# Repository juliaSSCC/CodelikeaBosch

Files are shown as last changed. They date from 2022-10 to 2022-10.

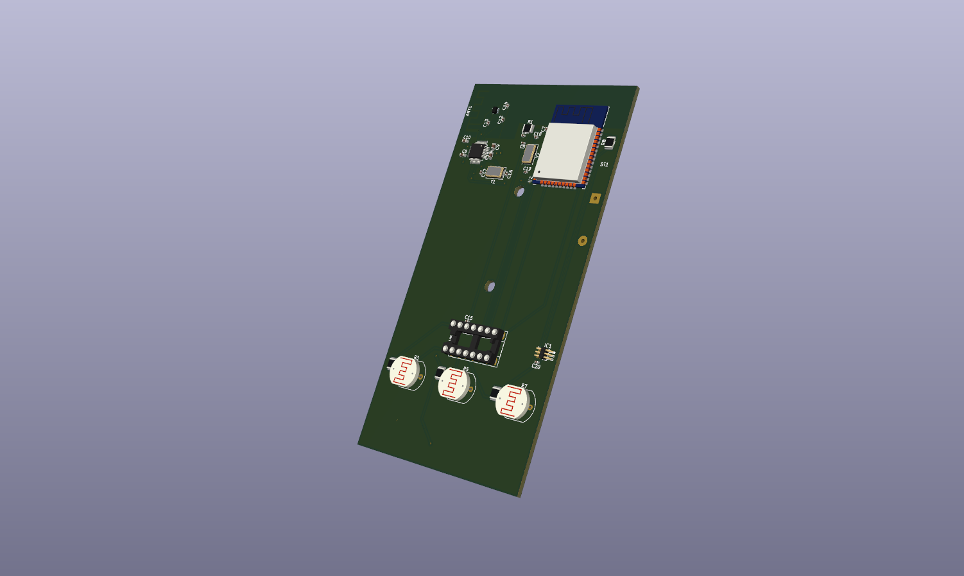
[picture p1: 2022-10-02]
board.png

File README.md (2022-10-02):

# Code #LikeABosch
## Features

### ESP32 based

* ESP32-WROOM-32D Microcontroller 
* Deep sleep mode (10uA)

### Smart position tracking

* BLE to better track postion
    * RSSI tracker for postion

### Smart temperature management

* Base temperature for each room
* Comfort temperature for each room

### Smart lighting

* Turn lights off in empty rooms
* LDR to measure light level
    * Three sensosrs to better capture the whole ambient

### Zigbee Transceiver

* Low power
* Deep Sleep mode (0.02uA)

### Supervisory system

* Shows current temperature
* Shows target temperature
* Shows ocupation
* Light level
* To be integrated to HA

### Power Supply

* Battery powered 3x(AAA)
* Buck converter (3.3V and 1.8V)

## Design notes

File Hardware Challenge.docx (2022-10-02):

João Anastácio da Rocha Almeida

Júlia Stutz Souza Carneiro de Campos

Introduction:

For our smart hardware project, our main goal in the winter is to use a base temperature choose by the house owner, for example 15 °C, in each room and then, predict by Markov Chain where and when the person is going to be during the day and in that way, the room temperature is going to be sensed by a TMP126 sensor and raised by an actuator (smart valve to turn on the heather) to put the temperature in a comfortable value, around 22 °C. We are also tracking the person’s position using Bluetooth Low Energy connected to a smart band and when someone enters the room, the lights will turn on depending on the LDR sensor to measure light level. That way, we decided to create a PCB (printed circuit board) with an ESP microcontroller, and our aim when talking about the user, is to decrease the gas and electricity consumption while being comfortable.

Project Bases:

The Markov chain is a mathematical model used to predict a next state based only on the current state, it is built upon the probability observed in a set of previous states used as training. In our research, we managed to find Markov chain implemented in use cases in microcontrollers, so it’s possible to used it in our routine prediction.

Each room is going to have a PCB (printed circuit board) with an ESP32-WROOM-32, 3 LDR sensors, 1 TMP126 sensor and 1 Low Power 2.4GHz Transceiver for ZigBee for the connections between all the ESPs in the house and a main server having the Markov Chain AI. We’ll be using 3 batteries to supply each PCB.

The ESP is perfect for this application, because it has a Bluetooth Low Energy, it is easy to configure and program, consequently, is easier to provide assistance and maintenance. It would be possible to add more features in the future, like a hydraulic system or safety project. During the design, we chose the ESP32-WROOM-32, because of the easiness, there is a lot of material for it, schematics, example, debug board, but in the real development it is not recommended since it’s.

TMP126 Low-Power is a temperature sensor, it has a configurable precision that defines the maximum and minimum range, we chose the excellent precision of -+0.4°C, which was the key factor, is very cheap, low power, is a different solution in the market and already has the SPI interface. Also, the LDR photoresistor is the most known way of sense the presence of light, is very easy to implement and is cheap, in conclusion, meets all needs.

For the transceiver communication between the microcontrollers, we are using the IC 2.4GHz Transceiver for ZigBee, and we chose the ZigBee/IEEE 802.15.4 protocol, because of the short distance reach, unlike LoRa that could have further interference, but still has a bigger range than Bluetooth, the delay is around 15ms-30ms which is low compared to Wi-Fi, is cheap, easy to configure and maintain compared to a Cellular IoT, and the low-power consumption, that usually works with 3.3V. Two AA batteries usually last 5 months and 2 years.

The installation is available and not that hard, after configuring the devices and the communication between them, the PCB is going to be added in the middle of the room, ideally attached to the ceiling. We chose this spot especially thinking of being far from heathers, the windows and the possibility of putting away from air conditioning. Since the project is about comfortable and, saving more money and energy, we thought in keep even more battery life by using sleep mode, so the price of energy spent is very low.

Cost:

The total cost of the PCB is 19.38 euros (€) per board to develop 1000 considering the manufacture and the components.

Gas Consumption Calculation:

We defined a house with an area of 100m² and 2.5m of height, so the total volume is 250m³. If we consider a big room in this house having 30m² (30 m²*2.5m = 75 m³) the volume is 30% of the total.

1 person/house:

Considering that the person stays in the biggest room for most of the time, the table of consumption is:

Gas Consumption (m^3/h) | Heat load (KW/h) | Efficiency of gas boiler (%) | Calorific Value of Gas (KW/m^3) | Volume (m^3) | Heat loss | Delta T (°C)
1,155990752 | 9,8837209 | 90 | 9,5 | 250 | 1 | 34
0,917992656 | 7,8488372 | 90 | 9,5 | 250 | 1 | 27

Expected Average Temp (°C) | Day Average Temp (°C) | Gas Cons. Per day (m^3) | Solution: Gas Cons. Per day (m^3)
22 | -12 | 27,74378 | 23,74541004
15 | -12 | 22,03182

30% of 27,74378 + 70% 22,03182 = 23,74541004

2 person/house staying most of the time in 2 rooms of 20m² (2*20m² = 40m²) the total volume of these rooms is 40% of the total:

Gas Consumption (m^3/h) | Heat load (KW/h) | Efficiency of gas boiler (%) | Calorific Value of Gas (KW/m^3) | Volume (m^3) | Heat loss | Delta T (°C)
1,155990752 | 9,8837209 | 90 | 9,5 | 250 | 1 | 34
0,917992656 | 7,8488372 | 90 | 9,5 | 250 | 1 | 27

Delta T (°C) | Expected Average Temp (°C) | Day Average Temp (°C) | Gas Cons. Per day (m^3) | Solution: Gas Cons. Per day (m^3)
34 | 22 | -12 | 27,74378 | 24,31660547
27 | 15 | -12 | 22,03182

40% of 27,74378 + 60% 22,03182 = 24,31660547

3 person/house staying most of the time in 3 rooms of 18m² (3*18m² = 54m²) the total volume of these rooms is 54% of the total:

Gas Consumption (m^3/h) | Heat load (KW/h) | Efficiency of gas boiler (%) | Calorific Value of Gas (KW/m^3) | Volume (m^3) | Heat loss | Delta T (°C)
1,155990752 | 9,8837209 | 90 | 9,5 | 250 | 1 | 34
0,917992656 | 7,8488372 | 90 | 9,5 | 250 | 1 | 27

Delta T (°C) | Expected Average Temp (°C) | Day Average Temp (°C) | Gas Cons. Per day (m^3) | Solution: Gas Cons. Per day (m^3)
34 | 22 | -12 | 27,74378 | 25,11627907
27 | 15 | -12 | 22,03182

54% of 27,74378 + 46% 22,03182 = 25,11627907

Before the Solution (€)

24,65202622

Solution: Gas Cons. Per day (kWh) | Solution: Price avarege in Eu per day (€) | Percentage of total savings (%)
269,8111791 | 21,09923421 | 14,41176471
276,3014824 | 21,60677592 | 12,35294118
285,387907 | 22,31733433 | 9,470588235

Electricity Consumption:

For the electric calculation, we considered that someone forgot at night a LED lamp lighted in a room and just saw on the next day at night, so the lamp was 20 hours on. If the room had an ESP with a Bluetooth connection and a light sensor, then the light would turn off without needing someone and would be only 8 hours on.

Consumption (kWh) | Wattage of the lamp (W) | Wattage of the lamp (kW) | Hours per Day (h) | Cost per kWh ($) | Total Cost ($)
0,24 | 12 | 0,012 | 20 | 0,14 | 0,0336
0,096 | 12 | 0,012 | 8 | 0,14 | 0,01344

Total Cost in a month ($) | Percentage of total savings (%)
1,008 | 60
0,4032

Applying our hardware solution, even more of this kind of case will be solved and still have the comfort of not having to turn the light on and off.

Bibliograph:

How IoT Devices Operates and Communicates Itself: A Brief Explanation - EE Times Asia. https://www.eetasia.com/how-iot-devices-operates-and-communicates-itself-a-brief-explanation/.

Top wireless standards for IoT devices - IoT Times. https://iot.eetimes.com/top-wireless-standards-for-iot-devices/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,focuses%20on%20wide%2Darea%20networks.

ctrfantennas. Lora vs ZigBee - C&T RF Antennas Manufacturer. https://ctrfantennasinc.com/lora-vs-zigbee/.

“Xbee/Zigbee Setup with Arduino and NodeMCU”. Arduino Project Hub, https://create.arduino.cc/projecthub/Neutrino-1/xbee-zigbee-setup-with-arduino-and-nodemcu-81f7fa.

Interfacing SX1278 Ra-02 LORA Module with Arduino. https://how2electronics.com/interfacing-sx1278-lora-module-with-arduino/.

Gas consumption for heating a house 100 m2: formulas and calculation example. https://engineer.decorexpro.com/en/otoplenie/project/rashod-gaza-na-otoplenie-doma-100-m2.html.

Natural Gas Price Statistics. https://ec.europa.eu/eurostat/statistics-explained/index.php?title=Natural_gas_price_statistics.

2022 Lighting Energy Cost Calculator. https://www.inchcalculator.com/lighting-energy-cost-calculator/.

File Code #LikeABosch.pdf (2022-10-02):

# Where2

Code #LikeABosch

João Anastácio da Rocha Almeida Júlia Stutz Souza Carneiro de Campos

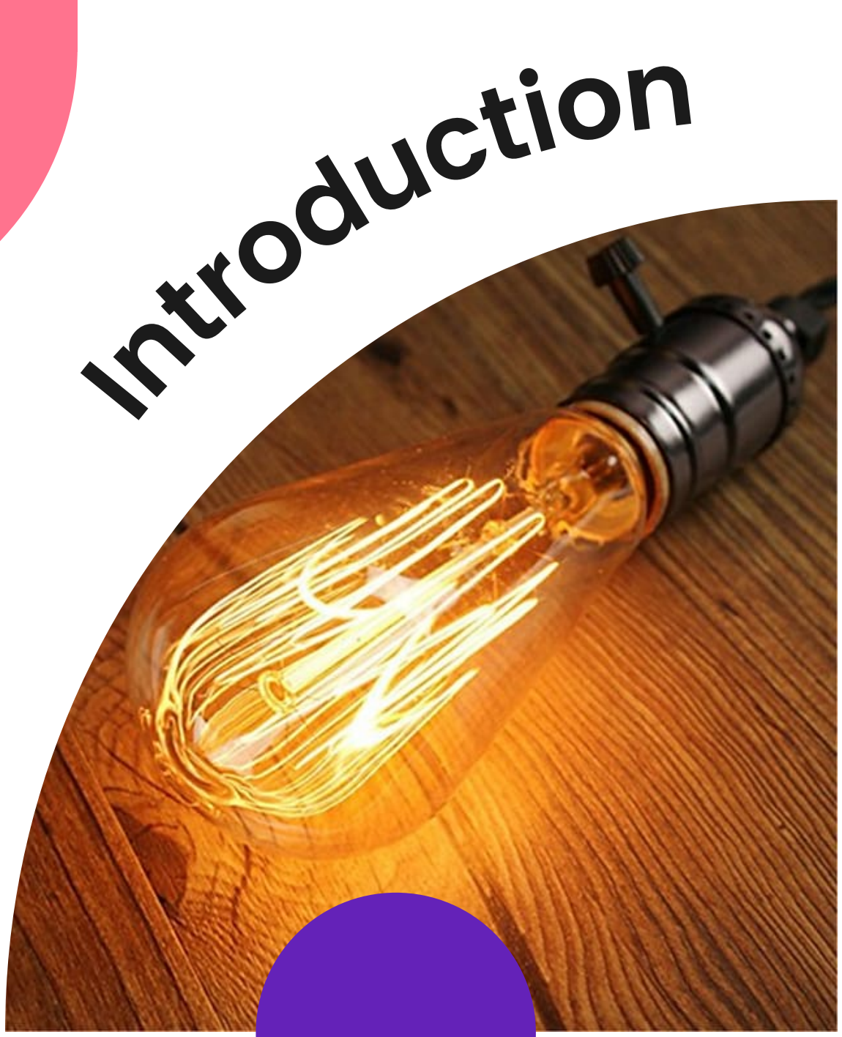
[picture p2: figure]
Introduction

Decrease the gas and
electricity consumption
while being comfortable

Create a PCB with an ESP
microcontroller

Aim

How

The house has a base temperature of 15 °C and a comfortable like 22 °C configured, we are going to predict by Markov Chain where and when the person is going to be during the day, and in that way, the room temperature is going to be sensed by a TMP126 sensor and raised by an actuator. We will also track the person

'

s position using BLE
connected to a smart band and when someone enters the room, the lights will turn on depending on the LDR sensor to measure light level.

### Example

# Project Bases

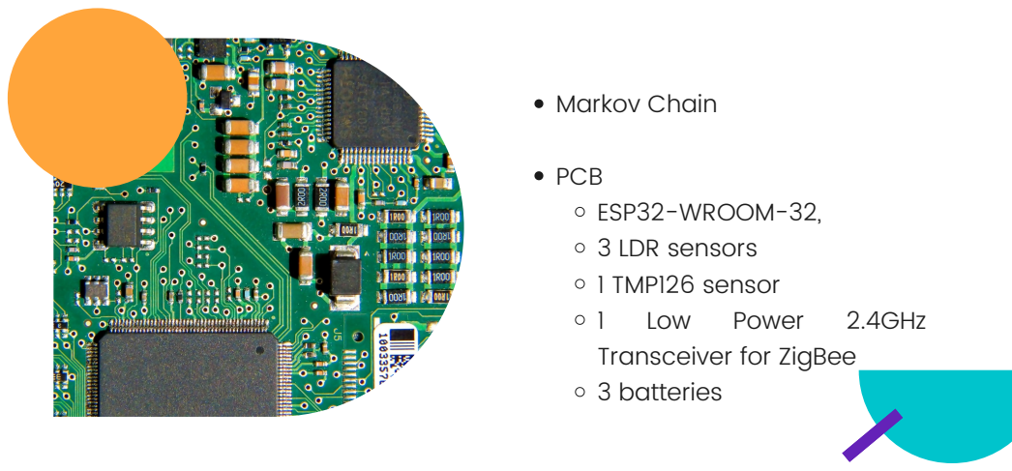
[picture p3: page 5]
Markov Chain

PCB
ESP32-WROOM-32,
3 LDR sensors
1 TMP126 sensor
1 Low Power 2.4GHz
Transceiver for ZigBee
3 batteries

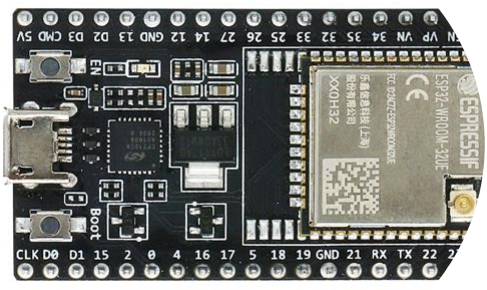
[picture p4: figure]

Bluetooth Low Energy
Easy to configure, program, and maintenance
Add more features

ESP32-WROOM-32

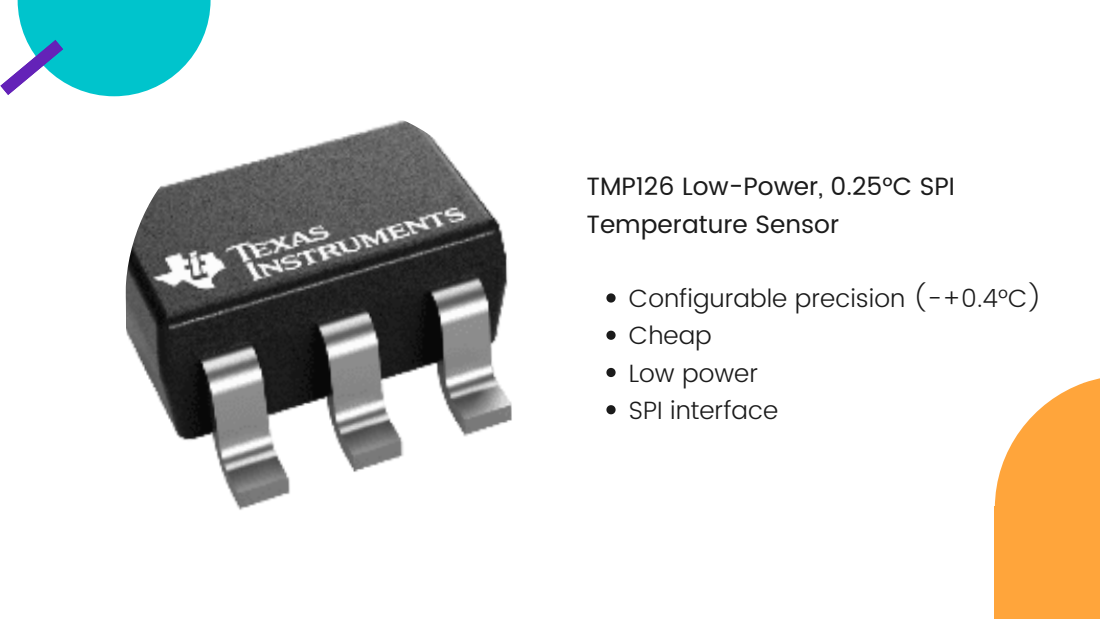
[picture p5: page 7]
Configurable precision (-+0.4°C) Cheap Low power SPI interface

TMP126 Low-Power, 0.25°C SPI
Temperature Sensor

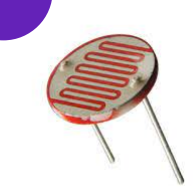
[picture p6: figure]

Sense the presence of light Easy to implement
Cheap

LDR Photoresistor

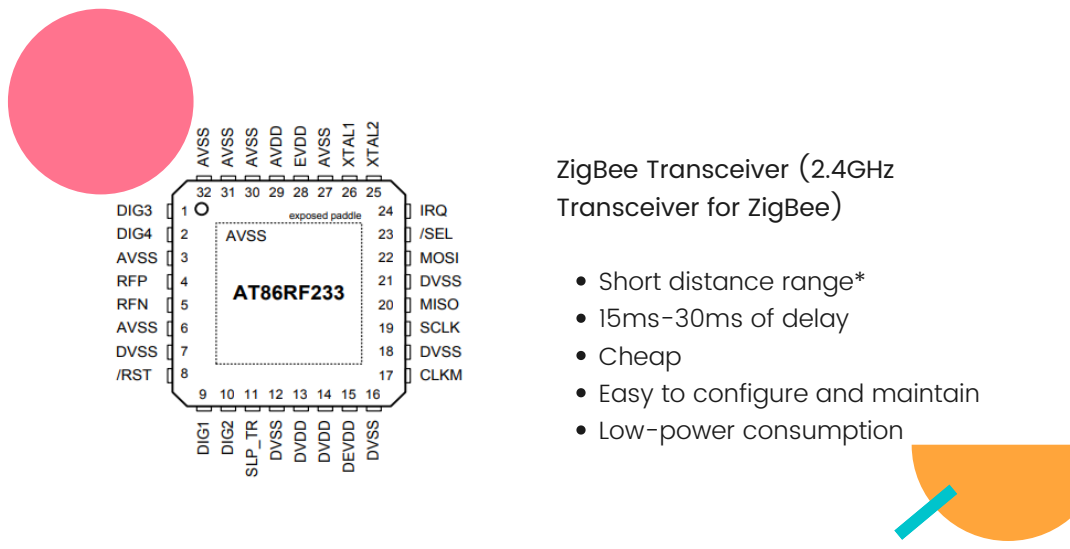
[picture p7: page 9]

ZigBee Transceiver (2.4GHz
Transceiver for ZigBee)

Short distance range*
15ms-30ms of delay
Cheap
Easy to configure and maintain
Low-power consumption

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
# Thank you!

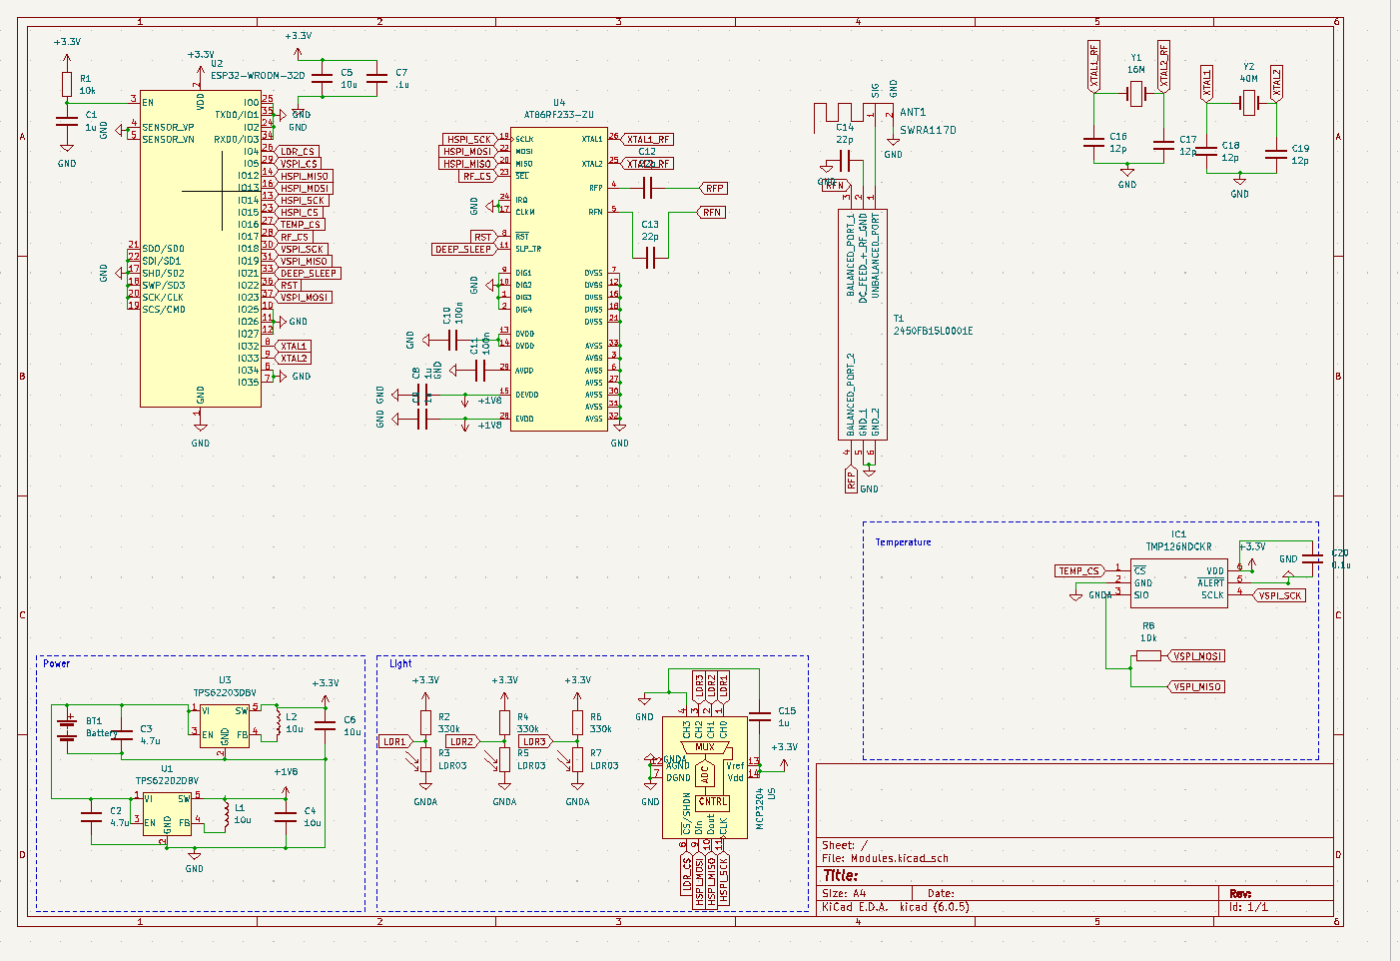
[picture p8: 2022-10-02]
schematics.png

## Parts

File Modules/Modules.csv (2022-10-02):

Source: | H:\Desktop\Desktop\C\Hackathon\Modules\Modules.kicad_sch
Date: | 01/10/2022 22:39:29
Tool: | Eeschema (6.0.5)
Generator: | C:\Program Files\KiCad\6.0\bin\scripting\plugins/bom_csv_grouped_by_value_with_fp.py
Component Count: | 41
Ref | Qnty | Value | Cmp name | Footprint | Description | Vendor
ANT1, | 1 | SWRA117D | SWRA117D | RF_Antenna:Texas_SWRA117D_2.4GHz_Right
BT1, | 1 | Battery | Battery | Battery:BatteryHolder_TruPower_BH-331P_3xAA | Multiple-cell battery
C1, C15, | 2 | 1u | C | Capacitor_SMD:C_0402_1005Metric | Unpolarized capacitor
C2, C3, | 2 | 4.7u | C | Capacitor_SMD:C_0402_1005Metric | Unpolarized capacitor
C4, C5, C6, | 3 | 10u | C | Capacitor_SMD:C_0402_1005Metric | Unpolarized capacitor
C7, | 1 | .1u | C | Capacitor_SMD:C_0402_1005Metric | Unpolarized capacitor
C8, C9, | 2 | 1u | C | Capacitor_SMD:C_0603_1608Metric | Unpolarized capacitor
C10, C11, | 2 | 100n | C | Capacitor_SMD:C_0603_1608Metric | Unpolarized capacitor
C12, C13, C14, | 3 | 22p | C | Capacitor_SMD:C_0402_1005Metric | Unpolarized capacitor
C16, C17, C18, C19, | 4 | 12p | C | Capacitor_SMD:C_0402_1005Metric | Unpolarized capacitor
C20, | 1 | 0.1u | C | Capacitor_SMD:C_0402_1005Metric | Unpolarized capacitor
IC1, | 1 | TMP126NDCKR | TMP126NDCKR | Connector_PinHeader_1.00mm:PinHeader_2x03_P1.00mm_Horizontal | Board Mount Temperature Sensors +/-0.25 C SPI temperature sensor with 175 C operation, CRC and slew-rate alert
L1, L2, | 2 | 10u | L | Inductor_SMD:L_6.3x6.3_H3 | Inductor
R1, R8, | 2 | 10k | R | Resistor_SMD:R_1210_3225Metric | Resistor
R2, R4, R6, | 3 | 330k | R | Resistor_SMD:R_1210_3225Metric | Resistor
R3, R5, R7, | 3 | LDR03 | LDR03 | OptoDevice:R_LDR_10x8.5mm_P7.6mm_Vertical | light dependent resistor
T1, | 1 | 2450FB15L0001E | 2450FB15L0001E | SamacSys_Parts:2450FB15L0001E | RF Transformer 1:1 6 Terminal SMD
U1, | 1 | TPS62202DBV | TPS62202DBV | Package_TO_SOT_SMD:SOT-23-5 | 300mA High-Efficiency Step-Down DC-DC Converter, fixed 1.8V output voltage, 2.5-6V input voltage, SOT-23-5
U2, | 1 | ESP32-WROOM-32D | ESP32-WROOM-32D | RF_Module:ESP32-WROOM-32 | RF Module, ESP32-D0WD SoC, Wi-Fi 802.11b/g/n, Bluetooth, BLE, 32-bit, 2.7-3.6V, onboard antenna, SMD
U3, | 1 | TPS62203DBV | TPS62203DBV | Package_TO_SOT_SMD:SOT-23-5 | 300mA High-Efficiency Step-Down DC-DC Converter, fixed 3.3V output voltage, 2.5-6V input voltage, SOT-23-5
U4, | 1 | AT86RF233-ZU | AT86RF233-ZU | Package_QFP:LQFP-32_5x5mm_P0.5mm | AT86RF233-ZU
U5, | 1 | MCP3204 | MCP3204 | Package_DIP:DIP-14_W7.62mm_Socket_LongPads | A/D Converter, 12-Bit, 4-Channel, SPI Interface, 2.7V-5.5V
Y1, | 1 | 16M | Crystal | Crystal:Crystal_SMD_0603-2Pin_6.0x3.5mm | Two pin crystal
Y2, | 1 | 40M | Crystal | Crystal:Crystal_SMD_0603-2Pin_6.0x3.5mm | Two pin crystal

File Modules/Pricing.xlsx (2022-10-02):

Column1 | Column2 | Column3 | Column4 | Column5 | Column6 | Column7 | Column8 | Column9
Source: | H:\Desktop\Desktop\C\Hackathon\Modules\Modules.kicad_sch
Date: | 01/10/2022 22:39:29
Tool: | Eeschema (6.0.5)
Generator: | C:\Program Files\KiCad\6.0\bin\scripting\plugins/bom_csv_grouped_by_value_with_fp.py
Component Count: | 41
Ref | Qnty | Value | Cmp name | Footprint | Description | unit price | 1000x unit price | total price
ANT1, | 1 | SWRA117D | SWRA117D | RF_Antenna:Texas_SWRA117D_2.4GHz_Right |  | 0 | 0 | 0
BT1, | 1 | Battery | Battery | Battery:BatteryHolder_TruPower_BH-331P_3xAA | Multiple-cell battery | 1.49 | 1.19 | 1190
C1, C15, | 2 | 1u | C | Capacitor_SMD:C_0402_1005Metric | Unpolarized capacitor | 0.1 | 0.019 | 38
C2, C3, | 2 | 4.7u | C | Capacitor_SMD:C_0402_1005Metric | Unpolarized capacitor | 0.1 | 0.019 | 38
C4, C5, C6, | 3 | 10u | C | Capacitor_SMD:C_0402_1005Metric | Unpolarized capacitor | 0.1 | 0.019 | 57
C7, | 1 | .1u | C | Capacitor_SMD:C_0402_1005Metric | Unpolarized capacitor | 0.1 | 0.019 | 19
C8, C9, | 2 | 1u | C | Capacitor_SMD:C_0603_1608Metric | Unpolarized capacitor | 0.1 | 0.019 | 38
C10, C11, | 2 | 100n | C | Capacitor_SMD:C_0603_1608Metric | Unpolarized capacitor | 0.1 | 0.019 | 38
C12, C13, C14, | 3 | 22p | C | Capacitor_SMD:C_0402_1005Metric | Unpolarized capacitor | 0.1 | 0.019 | 57
C16, C17, C18, C19, | 4 | 12p | C | Capacitor_SMD:C_0402_1005Metric | Unpolarized capacitor | 0.1 | 0.019 | 76
C20, | 1 | 0.1u | C | Capacitor_SMD:C_0402_1005Metric | Unpolarized capacitor | 0.1 | 0.019 | 19
IC1, | 1 | TMP126NDCKR | TMP126NDCKR | Connector_PinHeader_1.00mm:PinHeader_2x03_P1.00mm_Horizontal | Board Mount Temperature Sensors +/-0.25 C SPI temperature sensor with 175 C operation, CRC and slew-rate alert | 1.18 | 0.731 | 731
L1, L2, | 2 | 10u | L | Inductor_SMD:L_6.3x6.3_H3 | Inductor | 0.5 | 0.243 | 486
R1, R8, | 2 | 10k | R | Resistor_SMD:R_1210_3225Metric | Resistor | 0.36 | 0.051 | 102
R2, R4, R6, | 3 | 330k | R | Resistor_SMD:R_1210_3225Metric | Resistor | 0.36 | 0.051 | 153
R3, R5, R7, | 3 | LDR03 | LDR03 | OptoDevice:R_LDR_10x8.5mm_P7.6mm_Vertical | light dependent resistor | 1.14 | 0.382 | 1146
T1, | 1 | 2450FB15L0001E | 2450FB15L0001E | SamacSys_Parts:2450FB15L0001E | RF Transformer 1:1 6 Terminal SMD | 0.84 | 0.442 | 442
U1, | 1 | TPS62202DBV | TPS62202DBV | Package_TO_SOT_SMD:SOT-23-5 | 300mA High-Efficiency Step-Down DC-DC Converter, fixed 1.8V output voltage, 2.5-6V input voltage, SOT-23-5 | 1 | 0.793 | 793
U2, | 1 | ESP32-WROOM-32D | ESP32-WROOM-32D | RF_Module:ESP32-WROOM-32 | RF Module, ESP32-D0WD SoC, Wi-Fi 802.11b/g/n, Bluetooth, BLE, 32-bit, 2.7-3.6V, onboard antenna, SMD | 4.08 | 4.08 | 4080
U3, | 1 | TPS62203DBV | TPS62203DBV | Package_TO_SOT_SMD:SOT-23-5 | 300mA High-Efficiency Step-Down DC-DC Converter, fixed 3.3V output voltage, 2.5-6V input voltage, SOT-23-5 | 1 | 0.793 | 793
U4, | 1 | AT86RF233-ZU | AT86RF233-ZU | Package_QFP:LQFP-32_5x5mm_P0.5mm | AT86RF233-ZU | 4.28 | 4.28 | 4280
U5, | 1 | MCP3204 | MCP3204 | Package_DIP:DIP-14_W7.62mm_Socket_LongPads | A/D Converter, 12-Bit, 4-Channel, SPI Interface, 2.7V-5.5V | 4.56 | 3.45 | 3450
Y1, | 1 | 16M | Crystal | Crystal:Crystal_SMD_0603-2Pin_6.0x3.5mm | Two pin crystal | 0.87 | 0.515 | 515
Y2, | 1 | 40M | Crystal | Crystal:Crystal_SMD_0603-2Pin_6.0x3.5mm | Two pin crystal | 0.87 | 0.503 | 503
PCB manufactoring |  |  |  |  |  |  |  | 335.47
 |  |  |  |  |  |  |  | 19379.47
price per board |  |  |  |  |  |  |  | 19.37947

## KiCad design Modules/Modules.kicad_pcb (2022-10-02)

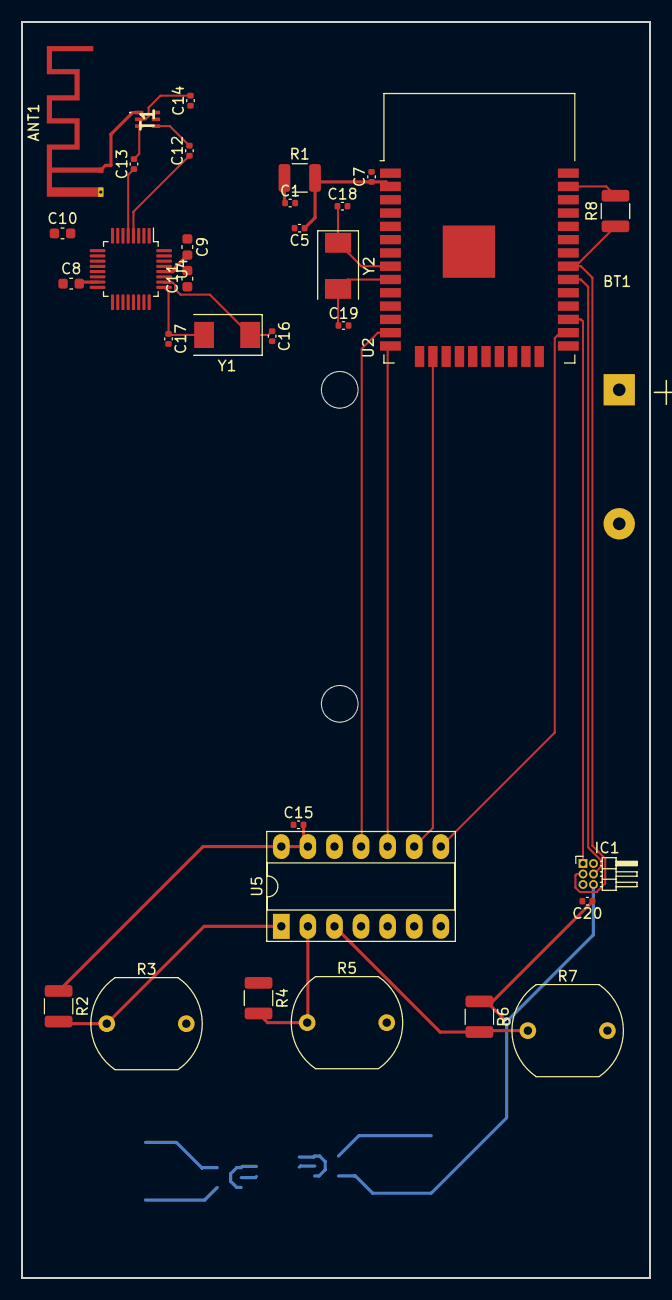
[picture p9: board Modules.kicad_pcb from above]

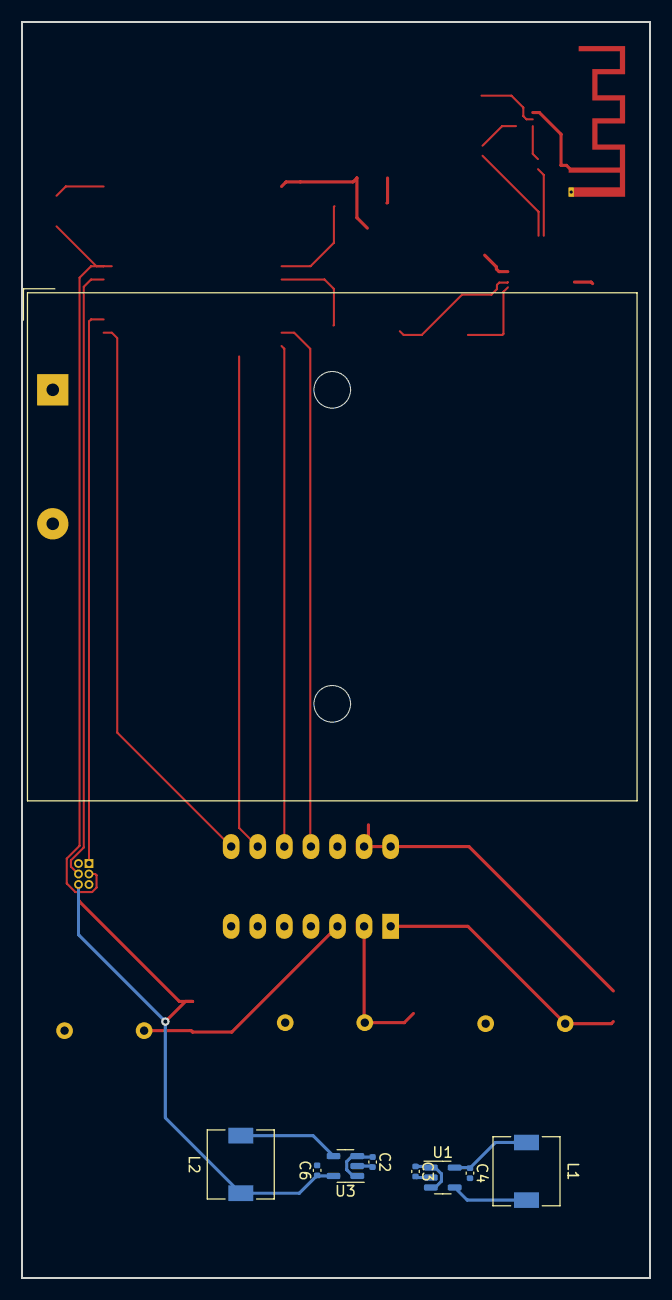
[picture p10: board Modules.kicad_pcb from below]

Board: 2 copper layers, 60.0 x 120.0 mm, 41 parts (9 on the bottom side), 36 nets.

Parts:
ANT1: SWRA117D; Texas_SWRA117D_2.4GHz_Right
BT1: Battery; BatteryHolder_TruPower_BH-331P_3xAA
C1, C15: 1u; C_0402_1005Metric
C2, C3: 4.7u; C_0402_1005Metric
C4, C5, C6: 10u; C_0402_1005Metric
C7: .1u; C_0402_1005Metric
C8, C9: 1u; C_0603_1608Metric
C10, C11: 100n; C_0603_1608Metric
C12, C13, C14: 22p; C_0402_1005Metric
C16, C17, C18, C19: 12p; C_0402_1005Metric
C20: 0.1u; C_0402_1005Metric
IC1: TMP126NDCKR; PinHeader_2x03_P1.00mm_Horizontal
L1, L2: 10u; L_6.3x6.3_H3
R1, R8: 10k; R_1210_3225Metric
R2, R4, R6: 330k; R_1210_3225Metric
R3, R5, R7: LDR03; R_LDR_10x8.5mm_P7.6mm_Vertical
T1: 2450FB15L0001E
U1: TPS62202DBV; SOT-23-5
U2: ESP32-WROOM-32D; ESP32-WROOM-32
U3: TPS62203DBV; SOT-23-5
U4: AT86RF233-ZU; LQFP-32_5x5mm_P0.5mm
U5: MCP3204; DIP-14_W7.62mm_Socket_LongPads
Y1: 16M; Crystal_SMD_0603-2Pin_6.0x3.5mm
Y2: 40M; Crystal_SMD_0603-2Pin_6.0x3.5mm

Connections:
+1V8: C4.1, C8.2, C9.2, L1.1, U1.5 (SW), U4.15 (DEVDD), U4.28 (EVDD)
+3V3: C5.1, C6.1, C7.1, C15.2, C20.1, IC1.6 (VDD), L2.1, R1.2, R2.1, R4.1, R6.1, U2.2 (VDD), U3.5 (SW), U5.13 (Vref), U5.14 (Vdd)
DEEP_SLEEP: U2.33 (IO21), U4.11 (SLP_TR)
GND: ANT1.2 (GND), C1.2, C5.2, C7.2, C8.1, C9.1, C10.1, C11.1, C14.1, C15.1, C16.2, C17.2, C18.2, C19.2, C20.2, IC1.5 (~ALERT), T1.5 (GND_1), T1.6 (GND_2), U2.1 (GND), U2.15 (GND), U2.38 (GND), U2.39 (GND), U4.3 (AVSS), U4.6 (AVSS), U4.7 (DVSS), U4.12 (DVSS), U4.16 (DVSS), U4.18 (DVSS), U4.21 (DVSS), U4.27 (AVSS), U4.30 (AVSS), U4.31 (AVSS), U4.32 (AVSS), U5.4 (CH3), U5.7 (DGND)
GNDA: IC1.2 (GND), R3.2, R5.2, R7.2, U5.12 (AGND)
HSPI_MISO: U2.14 (IO12), U4.20 (MISO), U5.10 (Dout)
HSPI_MOSI: U2.16 (IO13), U4.22 (MOSI), U5.9 (Din)
HSPI_SCK: U2.13 (IO14), U4.19 (SCLK), U5.11 (CLK)
LDR1: R2.2, R3.1, U5.1 (CH0)
LDR2: R4.2, R5.1, U5.2 (CH1)
LDR3: R6.2, R7.1, U5.3 (CH2)
LDR_CS: U2.26 (IO4), U5.8 (~CS/SHDN)
unnamed: ANT1.1 (SIG), T1.1 (UNBALANCED_PORT)
unnamed: BT1.1 (+), C2.1, C3.1, U1.1 (VI), U1.3 (EN), U3.1 (VI), U3.3 (EN)
unnamed: BT1.2 (-), C2.2, C3.2, C4.2, C6.2, U1.2 (GND), U3.2 (GND)
unnamed: C1.1, R1.1, U2.3 (EN)
unnamed: C10.2, U4.13 (DVDD), U4.14 (DVDD)
unnamed: C11.2, U4.29 (AVDD)
unnamed: C12.1, U4.4 (RFP)
unnamed: C13.1, U4.5 (RFN)
unnamed: C14.2, T1.2 (DC_FEED_+_RF_GND)
unnamed: L1.2, U1.4 (FB)
unnamed: L2.2, U3.4 (FB)
unnamed: U4.1 (DIG3), U4.2 (DIG4), U4.9 (DIG1), U4.10 (DIG2)
RFN: C13.2, T1.3 (BALANCED_PORT_1)
RFP: C12.2, T1.4 (BALANCED_PORT_2)
RF_CS: U2.28 (IO17), U4.23 (~SEL)
RST: U2.36 (IO22), U4.8 (~RST)
TEMP_CS: IC1.1 (~CS), U2.27 (IO16)
VSPI_MISO: IC1.3 (SIO), R8.1, U2.31 (IO19)
VSPI_MOSI: R8.2, U2.37 (IO23)
VSPI_SCK: IC1.4 (SCLK), U2.30 (IO18)
XTAL1: C18.1, U2.8 (IO32), Y2.1
XTAL1_RF: C16.1, U4.26 (XTAL1), Y1.1
XTAL2: C19.1, U2.9 (IO33), Y2.2
XTAL2_RF: C17.1, U4.25 (XTAL2), Y1.2

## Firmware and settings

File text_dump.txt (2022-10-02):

sensor of humidity 
design a sensor
complex solution
less items 

sensor de temperatura
bluetooth - esp
luminosidade - ldr
motor de valvula 
lcd mostrando as configuraçoes


create cooridnate system
set sensors on coordinates
set rooms boundry

modulo com ble e temp

valvula automatica


Markov chain research:
Markov chains, named after Andrey Markov, are mathematical systems that hop from one "state" (a situation or set of values) to another. For example, if you made a Markov chain model of a baby's behavior, you might include "playing," "eating", "sleeping," and "crying" as states, which together with other behaviors could form a 'state space': a list of all possible states. In addition, on top of the state space, a Markov chain tells you the probabilitiy of hopping, or "transitioning," from one state to any other state---e.g., the chance that a baby currently playing will fall asleep in the next five minutes without crying first.
Explanation: https://setosa.io/ev/markov-chains/
Experiment: https://ieeexplore.ieee.org/document/7831684
Experiment: https://www.jstor.org/stable/26169319
Experiment: PDF in my computer


Gas consumption research:
https://engineer.decorexpro.com/en/otoplenie/project/rashod-gaza-na-otoplenie-doma-100-m2.html
Worcester Greenstar CDi 25 Cdi	Condensing	Gas	90.0%  --> https://www.homeheatingguide.co.uk/efficiency-tables?model=010263
Worcester Greenstar CDi 25 Cdi




Communication protocols ioT
advantages, desavantages and use.
How much data will you need to transfer? low
How much power is required? low - battery
How far is the data source from the internet? sensor sending message to the servidor 
How high is the cost for service? low
Where are the devices going to be used? 
Will they be used inside a building or outside? Inside

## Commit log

2022-09-30 Fixed README
    [text_dump.txt]
2022-10-01 Added schematic and layout prototype
    [Modules.kicad_pcb, Modules.kicad_sch]
2022-10-02 First concept of the routed board
    [Modules.kicad_pcb, Modules.kicad_sch]
2022-10-02 added base documantation
    [Gas and Electric calculation.xlsx, text_dump.txt]
2022-10-02 added temp sensor datasheet
2022-10-02 Added pricing calculation
    [Modules.csv, Pricing.xlsx]
